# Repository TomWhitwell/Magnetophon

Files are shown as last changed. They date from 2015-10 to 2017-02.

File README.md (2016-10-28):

# Magnetophon  
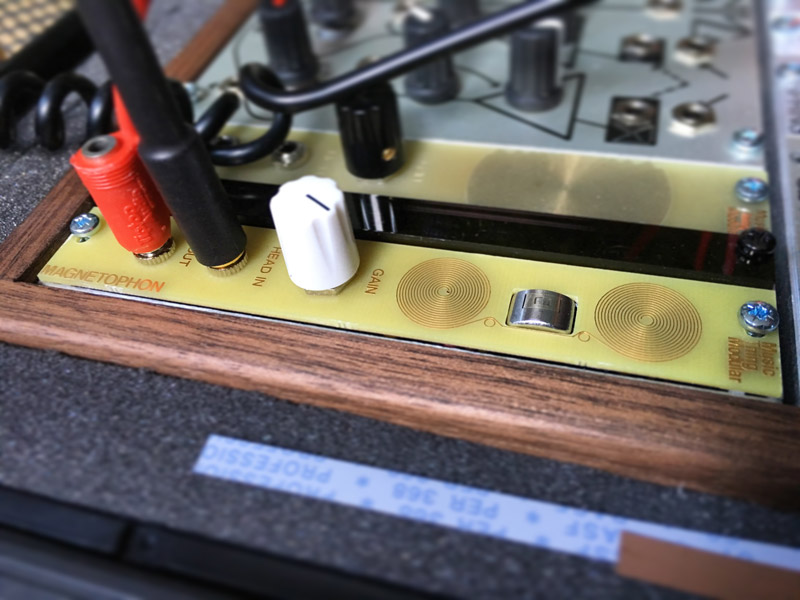
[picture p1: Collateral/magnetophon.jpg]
  
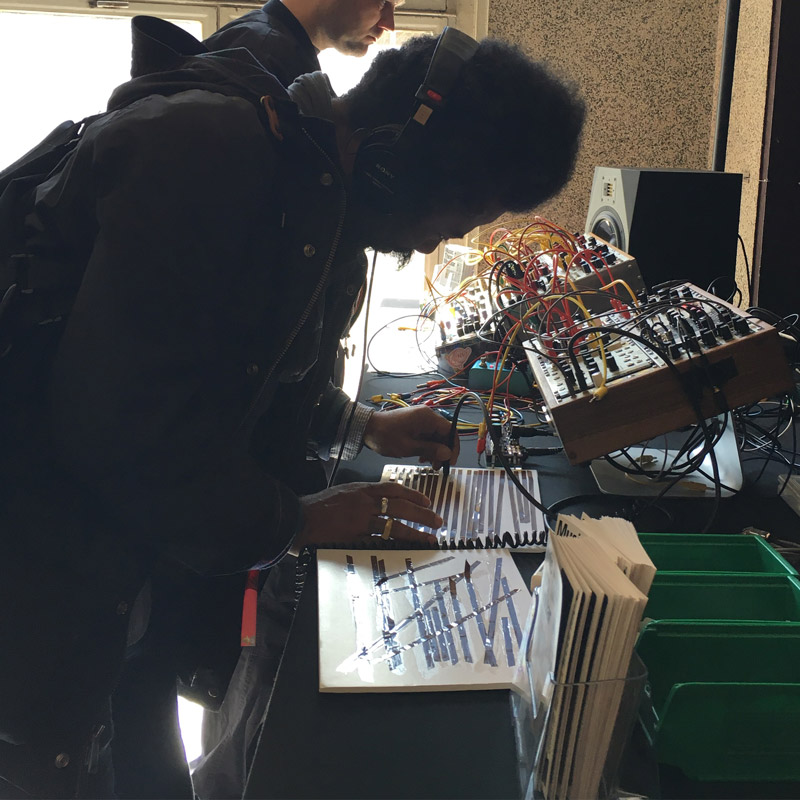
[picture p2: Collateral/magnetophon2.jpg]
    

With a mono cassette head in the panel and a NAB equalised ampli er circuit, Magnetophon is a cassette player without the transport mechanism. Try rubbing old cassette tapes on the panel, or attach a head on a wire to recreate Nam June Paik’s
Random Access or Laurie Anderson's Tape Bow Violin. 

[Schematic](https://github.com/TomWhitwell/Magnetophon/blob/master/Collateral/Magnetophon_schematic.pdf)

[Magnetophon is in this video from SuperBooth16 in Berlin](https://youtu.be/UVMrQejVZlw?t=4m26s) 

[Magnetophon vs Nagra audio torture test. The Nagra sounds better(!) but it gets fun when the Magnetophon head starts moving](https://soundcloud.com/musicthing/nagra-v-magnetophon)

BOM: 

- 2 x Thonkiconn Sockets 
- 1 x 50k Alpha Potentiometer (from Thonk, with bushing)  
- 1 x 10 pin 5x2 Euro power header 
- 1 x TL072 op amp 
- 1 x CTH1M MONO cassette playback head
- 2 x Poly Fuses (100ma blow or higher) 
- 2 x 1N4001 diodes 
- 1 x 47uf Electrolytic Capacitor* 
- 2 x 10uf Electrolytic Capacitors* 
- 2 x 100nf Ceramic Capacitor 
- 1 x 15nf Polybox Capacitor
- 1 x 200k resistor 
- 1 x 3.6k resistor 
- 1 x 2.2k resistor 
- 1 x 470R resistor 
- 2 x 200R resistor 
- Notes: 
- C7 is NOT required but a space is left on the board in case you have any oscillation in the first op amp stage. 
- *Electo caps should be short - 7mm tall - to fit between the boards. Otherwise, you can mount them on the back if you are careful of polarity. 

Status: 
- May 2016: Rev 1 (= Proto 2 with silkscreen tweaks) should be good to build. 
- Proto 2 works well. 
- Proto 2 designed and sent to fab 
- Proto 1 used for 4 days straight at SuperBooth 
- Proto 1 built, needed extra capactitor to kill huge ultrasonic oscillation
- Not verified 
- January 2016 Prototype sent for manufacture 
- October 2015 Designed 

Named after the [AEG Magnetophon](http://www.aes.org/aeshc/docs/recording.technology.history/tape.html), the first commercial tape recorder, revealed at the 1935 Radio Fair in Berlin. 

  
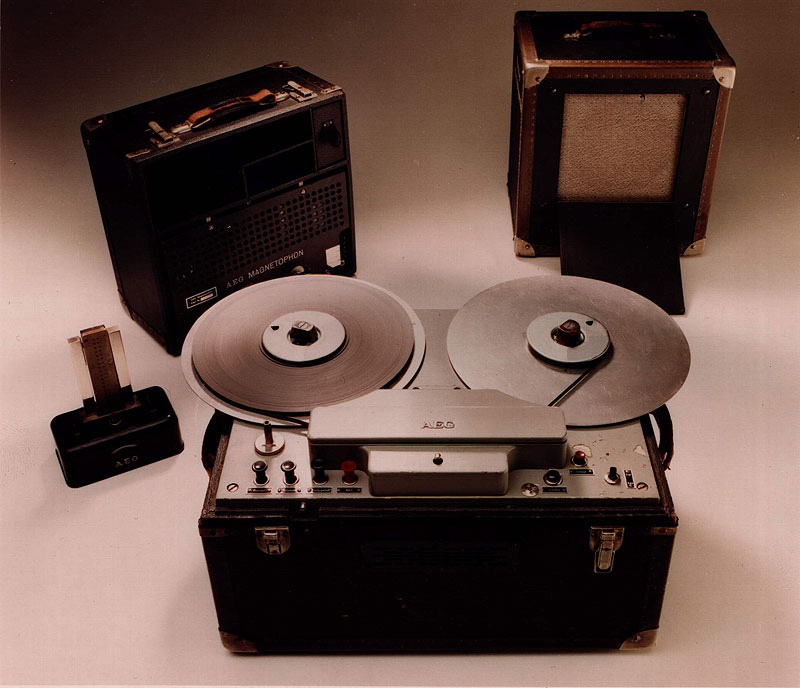
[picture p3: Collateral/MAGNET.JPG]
  
([Image via AES](http://www.aes.org/aeshc/docs/recording.technology.history/tape.html))

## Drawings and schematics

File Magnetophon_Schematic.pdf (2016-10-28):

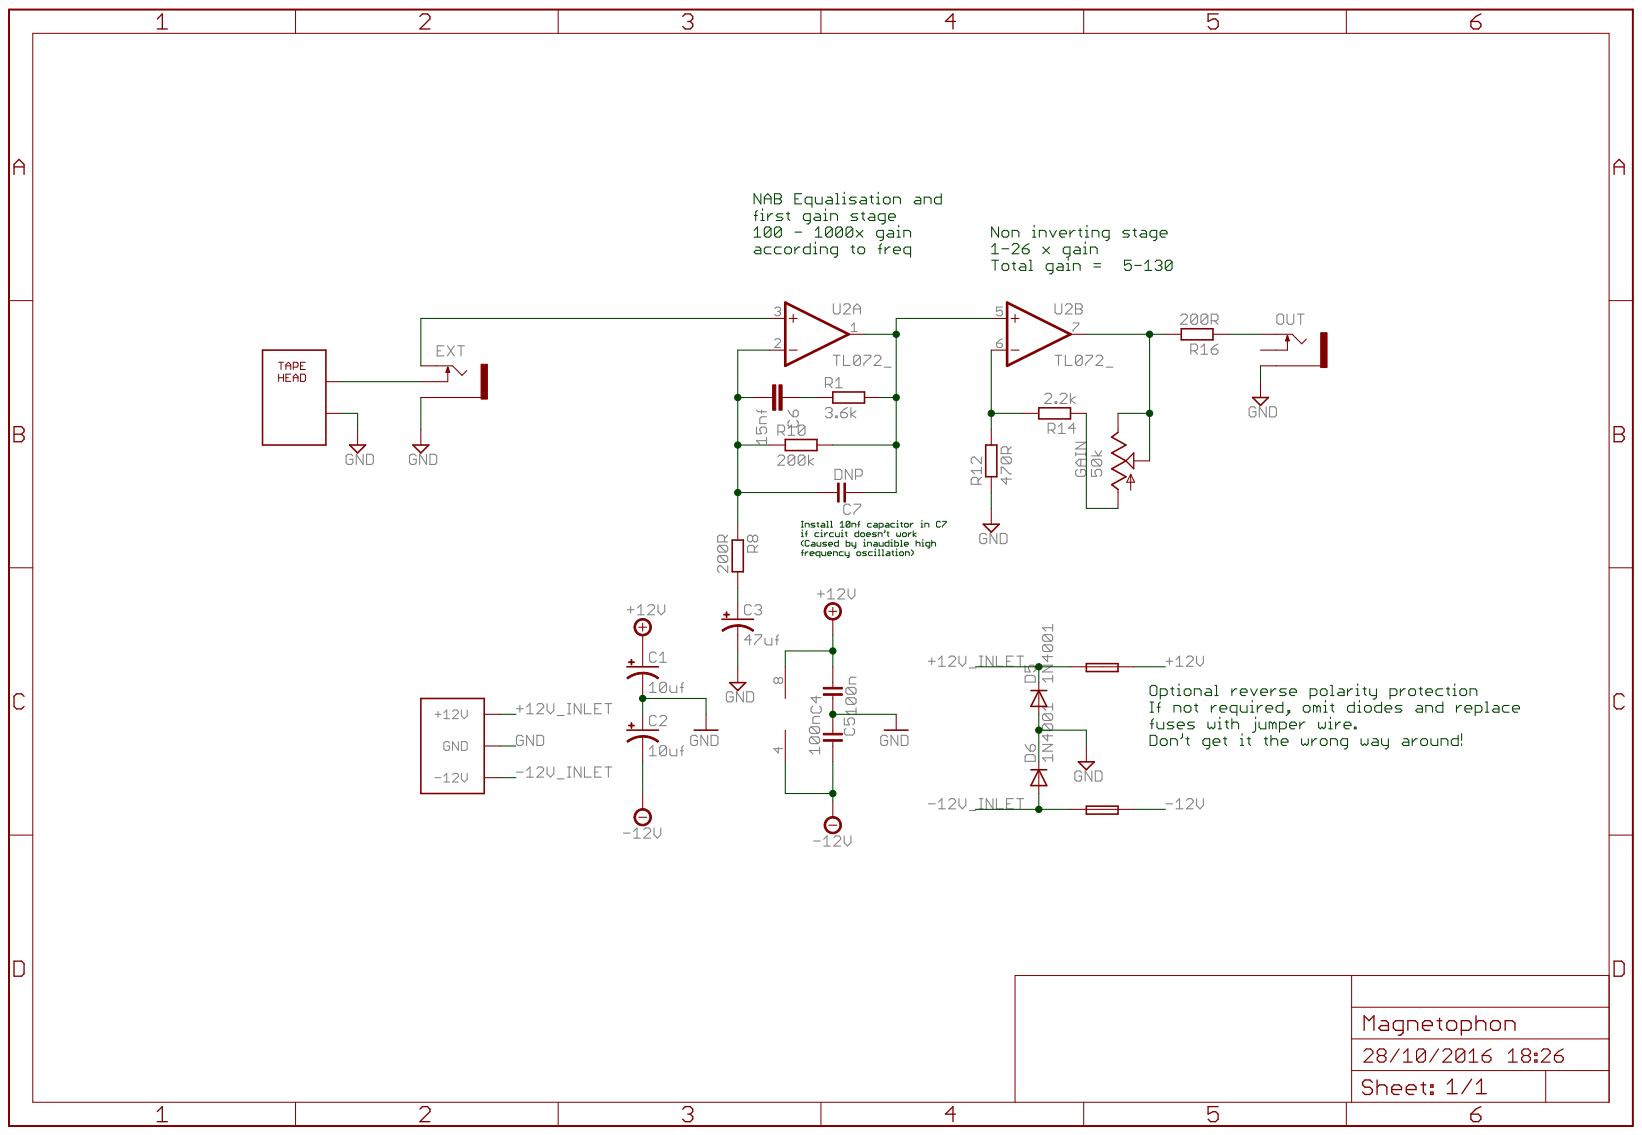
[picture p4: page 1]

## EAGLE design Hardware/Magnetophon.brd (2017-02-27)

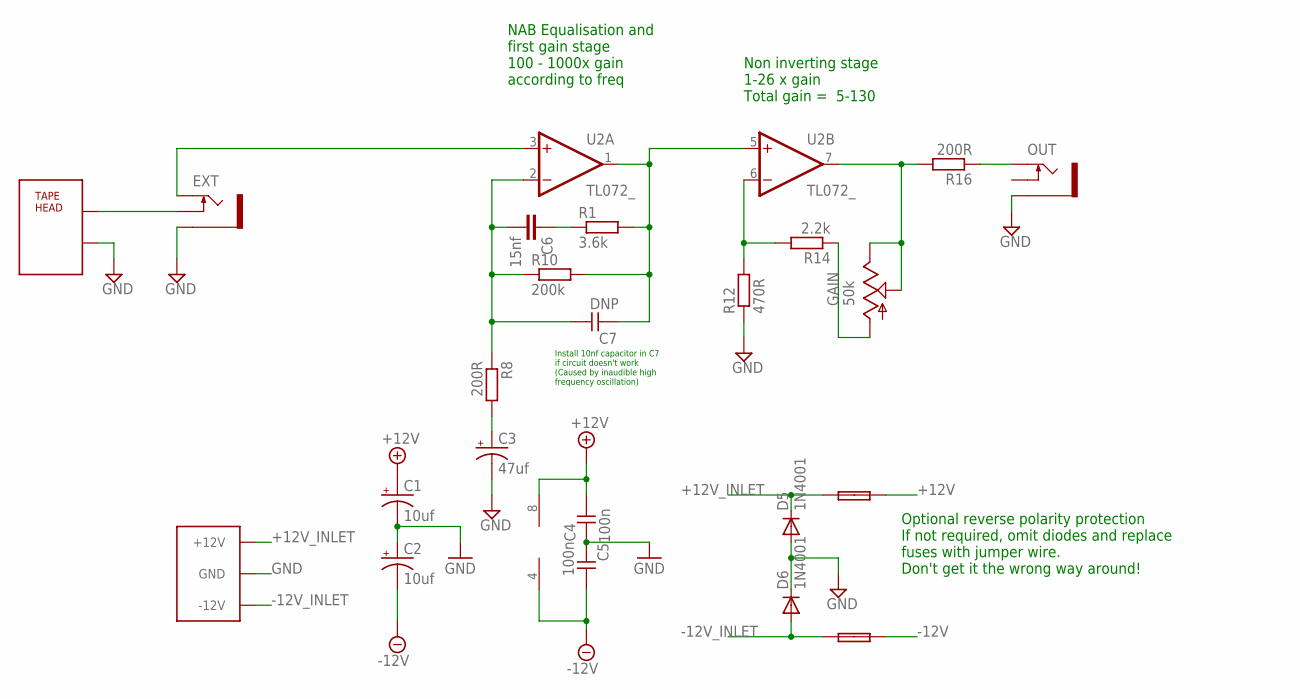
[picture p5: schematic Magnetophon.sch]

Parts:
1: FUSE; C050H075X075
C1, C2: 10uf; CPOL-RADIAL-10UF-25V
C3: 47uf; CPOL-RADIAL-10UF-25V
C4, C5: 100n; C050-024X044
C6: 15nf; C050-030X075
C7: DNP; C050-024X044
D5, D6: 1N4001; DO41-10
EXT: THONKICONNNEW; WQP-PJ301M-12_JACK
FUSE: FUSE; C050H075X075
GAIN: 50k; EVUF
OUT: THONKICONNNEW; WQP-PJ301M-12_JACK
R1: 3.6k; 7MM_RESISTOR
R8, R16: 200R; 7MM_RESISTOR
R10: 200k; 7MM_RESISTOR
R12: 470R; 7MM_RESISTOR
R14: 2.2k; 7MM_RESISTOR
U2: TL072_; DIL08
U$1: MONO_CASSETTE_HEAD
U$2: EURO_POWER_LOCK; EURO_PWR_HEADER_LOCK

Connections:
+12V: 1.2, C1.1 (+), C4.1, U2.8 (V+)
+12V_INLET: 1.1, D5.C, U$2.POS1 (+12V), U$2.POS2 (+12V)
-12V: C2.2 (-), C5.1, FUSE.2, U2.4 (V-)
-12V_INLET: D6.A, FUSE.1, U$2.NEG1 (-12V), U$2.NEG2 (-12V)
FROMHEAD: EXT.P$2_SWITCH (SWITCH), U$1.P$1
GND: C1.2 (-), C2.1 (+), C3.2 (-), C4.2, C5.2, D5.A, D6.C, EXT.P$3_SLEEVE (SLEEVE), OUT.P$3_SLEEVE (SLEEVE), R12.1, U$1.P$2, U$2.GND1 (GND), U$2.GND2 (GND), U$2.GND3 (GND), U$2.GND4 (GND), U$2.GND5 (GND), U$2.GND6 (GND)
unnamed: C6.2, C7.1, R8.1, R10.1, U2.2 (-IN)
unnamed: C7.2, R1.2, R10.2, U2.1 (OUT), U2.5 (+IN)
unnamed: GAIN.1 (A), R14.1
unnamed: R12.2, R14.2, U2.6 (-IN)
unnamed: C3.1 (+), R8.2
unnamed: GAIN.2 (S), GAIN.3 (E), R16.2, U2.7 (OUT)
unnamed: C6.1, R1.1
unnamed: OUT.P$1_TIP (TIP), R16.1
TOAMP: EXT.P$1_TIP (TIP), U2.3 (+IN)

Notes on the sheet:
NAB Equalisation and first gain stage 100 - 1000x gain according to freq
Non inverting stage 1-26 x gain Total gain = 5-130
Optional reverse polarity protection If not required, omit diodes and replace fuses with jumper wire. Don't get it the wrong way around!
Install 10nf capacitor in C7 if circuit doesn't work (Caused by inaudible high frequency oscillation)

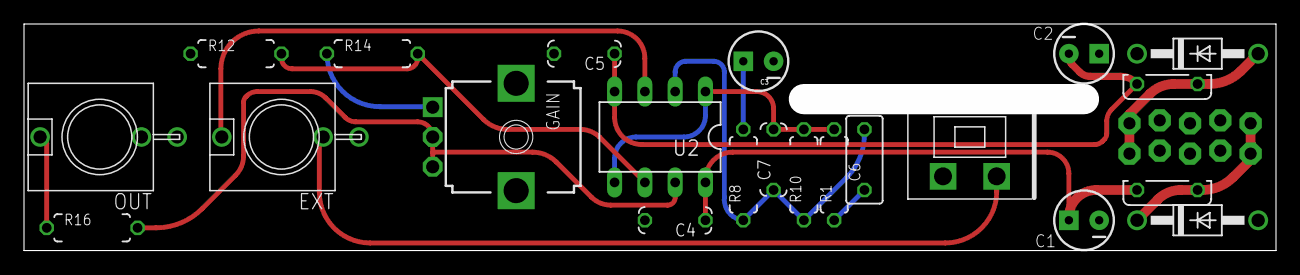
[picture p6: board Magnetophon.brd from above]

Board: 4 copper layers, 105.0 x 19.0 mm, 23 parts (1 on the bottom side), 15 nets.

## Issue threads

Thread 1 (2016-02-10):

huge 100khz oscillation

TomWhitwell, 2016-02-10:
cured by 10n cap between pin 1&2 of op amp

Closed 2016-05-03.

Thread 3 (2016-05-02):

Prototype 2 PCB: Silkscreen issues

TomWhitwell, 2016-05-02:
No electro cap sizes
fuze markings are messy

Closed 2016-05-03.

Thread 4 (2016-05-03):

Issues with rev2 PCB

TomWhitwell, 2016-05-03:
Build with
R12 2.2k
R14 2.2k
Pot 50k
No c7
= Works well

Closed 2016-05-03.

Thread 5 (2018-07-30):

MTM Magnetophon

boombipbass, 2018-07-30:
I just soldered together a Megnetophon, so far Ive succeeded the Mikrophonie and the Music thing,
I am sure I've checked the making the module manual quite close but it doesn't generate any sound from my tape loops I've stuck on a piece of wood with the 2nd head, also the 1st head is not responding nor do I get a feedback hum from other modules form the output.

How could I check with a multimeter if the module is getting power in the circuitry?

Best bbb

boombipbass, 2018-07-30:
Ok well Ive just learned that you should atleast never put a just soldered module in your Eurorack..

Oups haha. Well atleast Ive learned something on my own, but now to think, I do have a multimeter or are there better solutions?

Best bbb

TomWhitwell, 2018-07-30:
If the module is completely dead, check the op amp chip is getting power - look at the data sheet (google TL072) and see which pins need +v and -v. Put the black probe on -v and the red probe on +v and you should see around 23-24volts. Check the chip is correctly oriented.

boombipbass, 2018-07-30:
Is this the data sheet? https://github.com/TomWhitwell/Magnetophon/blob/master/Magnetophon_Schematic.pdf

How do I know which is 5+ and -6 of the 8 pins? Its faceing the right way aswell as the OpAmp Holder.

Also how can I check if the TapeHead/minijack male is working with my Multimeter?

Thanks for helping me ^-^

Love your stuff!

TomWhitwell, 2018-07-30:
It’a on page 5 here : http://www.ti.com/lit/ds/symlink/tl072.pdf

(NOT page 4, that’s the tl071)

boombipbass, 2018-07-30:
Ah yes by following the copper route on the backside I already found out that R17 connected with 7 and thus which 5 must be since that one connected to the OpAmp nr. 1 in the schematics, wow learning new things here 🗡

boombipbass, 2018-07-30:
Strange that a black probe must be on the - and a red on the + since the ribbon is otherwise in color :)

boombipbass, 2018-07-30:
is it AC of DC?

boombipbass, 2018-07-30:
Nope not with AC nor with DC its getting 23/24 volts. On my multimeter set to 20 V.
I've checked with the OpAmp holder aswell as with the OpAmp itself :- (

boombipbass, 2018-07-30:
I do have to say I havent put it in my modular system, because I read thats stupid and I should actuaklly use a Bench power supply or some sort?

boombipbass, 2018-07-30:
I am sure all connections are soldered good though

boombipbass, 2018-07-30:
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

boombipbass, 2018-07-30:
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
Also on modulargrid it says this about the magnetophon which i dont udnerstand?

TomWhitwell, 2018-07-30:
That just means nobody has put the power specs into modular grid - it draws around 25mA or less on each rail

boombipbass, 2018-07-30:
Ok thats good to know, then the only thing I am wondering, do I need a Bench power supply to test DIY kits or not?

And should I recheck the module in the case with the IC to see if it gets 24 volts, it has been in the case and no smoke or explosions so thats a good thing :)

boombipbass, 2018-07-30:
Ok well checked it with Power on and still no Votlage, any solution? :)

realitycontrol, 2018-07-30:
If you're measuring between the +V and -V pin on the OpAmp using the 20V DC setting on your multimeter (as stated above); you will not get a reading.

You want to be using the 200V setting when you are expecting anything over 20V.
If using the 20V setting you could separately measure the + and - pins to ground.

zerojardins, 2020-04-29:
As I can see on the pictures of your board, you misplaced both fuses with the two 100n capacitors (C4 & C5)

hope that helps

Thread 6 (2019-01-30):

Omit panel mounted tape head?

dujoducom, 2019-01-30:
Would there be any negative effects of omitting the panel mounted tape head (just not soldering it on)? I'd like to make the wand instead, only have one tape head, and see basically no reason why I personally would utilize the panel mounted one.

derridada, 2020-07-11:
so - I put this together and the tape head simply doesn't seem to work, but the Head input does. I'm thinking of pulling the tapehead and building a wand. Did you build it omitting the tapehead on the panel? If so - how did it work out?

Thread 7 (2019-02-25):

Powering the module

Terbijn, 2019-02-25:
Hi,

I'm putting together an installation and don't have a proper Eurorack power supply at hand right now. Do you think the module could be powered with batteries? If so, is there something you recommend? The exhibition would be on for 7 days and I think the module would be in active use for not more than 3 hours during that time.
Also, are there instructions for building the wand?

Thank you very much!

Best wishes,
Oliver

TomWhitwell, 2019-02-26:
I've never tried it, but you might be able to use two 9v batteries back to back

Closed 2019-02-26.

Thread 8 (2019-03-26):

Magnetophon playback

metalthrow, 2019-03-26:
I have a Magnetophon with an external playback head. When rubbing the tape head across tape stuck to a sheet of foamcore or hard paper, I've tried both, it just sounds like the back of a credit. I'm wondering if anyone has experimented with this and knows if it is possible to obtain the cassette's actual sounds on it when manually pushing the head on to the tape?

TomWhitwell, 2019-03-26:
Hi, Sorry to hear that. I've tested it both with cassette tape and with 1/4" tape from a Nagra.
Clearly the 1/4" tape is much easier, because it's a single mono signal going one direction along the tape.
However, I did get it to work roughly with cassette tape, although the signal was substantially lower in output, and your have four simultaneous tracks -  left & right x 2 (backwards & forwards) on each bit of tape, which can quite quickly become noise.
A secondary issue was that when I tried it with spoken word tapes (language cassettes) I quickly realised that for every inch of speech there might be 3-4 inches of silence, which makes the whole thing a bit tricky.
You're getting roughly 2 inches of tape per second of sound - which should give an idea how fast to move the head.

metalthrow, 2019-03-27:
Thank you for the reply so promptly. I'm going to try out some 1/4'' tape and see fi that helps. I also noticed in the demo video there something on top the tape , did you glue it to the paper? also does foamcore vs. paper make a difference

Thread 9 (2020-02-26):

Tape Wand

tetsugakusha66, 2020-02-26:
Hi Tom!
I'm having a big issue with my Magnetophon.
The tape head in the module itself works all right, but as soon as I plug in anything into the Head In jack, it's noise city.
I soldered the tape head to a 3m long patch cable and when it's plugged in the ground noise is massive. I'm assuming this is a ground noise problem, because when I touch nearly anything on my desk, the noise is attenuated slightly. The tape head on the wand functions correctly so I don't think that I have soldered it in backwards.
Could this be due to the length of the tape head wand or the fact that I used a patch cable instead of a guitar cable?
I tried to populate the DNP spot with a 10nf cap, but to no avail.
Any advice you could offer would be greatly appreciated!

snoopyart, 2020-06-25:
Exactly the same issue for me. I also used a patch cable (high quality though, with shielding). Also tried the 10nf cap. Also no way to get it working with the wand. No idea. Checked all solder points etc. but the module itself works perfectly fine with the internal head... Any help appreciated! THX!

magnesi, 2020-07-23:
Same here. Any help would be hugely appreciated as I'm trying to use it for a college project.

TomWhitwell, 2020-07-24:
Re: ground noise problems for @magnesi @snoopyart @tetsugakusha66
I connected mine using (from memory) a balanced cable - i.e. two internal connectors and one shield. The internal connectors went from tip/ring on the socket to the two pins on the tape head. The orientation doesn't seem to matter. The shield is connected at the socket end. At the tape head end I tried to connect it to the metal frame of the tape head, but I'm not sure this was super successful. I found it very hard to solder to the tape head body, so I stripped a bit of the shield and put it next to the tape head body, then held it in place with heat shrink.
I don't if this will solve your problems, but it's worked OK for me.

magnesi, 2020-07-25:
Thanks Tom

esoterydactyl, 2022-06-11:
Very happy to have found this issue open, as I have been driving myself absolutely crazy this afternoon trying to understand what I've done wrong with the kit!  I'll see if I can work out a balance cable.  If this turns out to be the solution, we should consider updating documentation to recommend it!

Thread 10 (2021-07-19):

Some notes from build experiences

mroystonward, 2021-07-19:
Hi not actually an issue but it does address several existing issues (open and closed) and therefore might be of use to some.

I've successfully built this module using these tape-heads - https://www.aliexpress.com/item/33005387634.html?spm=a2g0s.12269583.0.0.513062e8RFe37r

To fit in the panel, I removed the metal guide/fork and then bent the rest of the metal around the tape head body. I soldered trimmed off component legs to the tape head legs, and then mounted in the PCB/panel before soldering. The bent around metal frame helps it sit in place but I'm going to use a dab of epoxy to make it a bit more solid.

I did have no end of trouble at first. It didn't *sound* like oscillation but the extra capacitor definitely helped.

There is a little interference/hum when holding tape near the head but it's acceptable.

For the tape wand, I again removed the guide forks and bent the rest of the metal around the tape head. I used stereo/2-core shielded cable, as recommended in an issue above. Each core was soldered to a tape head leg with the shield trapped and soldered between the extra-bent-around metal and the tape head. I then used excessive amounts of heat-shrink (descending in size to fit both the head and cable) to keep it all secure, neat, insulated, etc. On the other end, a 3.5mm mono jack plug with one of the cores wired to the tip and both the other core and shield wired to the sleeve connection.

Basically, the wand was unusable when I first tried with mono cable but works fine with a stereo cable. Again, a bit of hum when actually holding the tape head but it's all workable.

Anyway, hope this helps others and thanks for making the module open source etc.

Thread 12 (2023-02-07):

No Audio, Bad Humming

acoostix, 2023-02-07:
I've received and built a Magnetophon kit from Thonk. PCB v1.1

I fully traced out all components against the schematic found on this git - while some components are not present on the board, the components that are are connected are connected correctly. Good solders. TL072 is mounted correctly, electronlytic caps are mounted correctly.

I can confirm that the TL072 is reading 24 volts at its VCC pin.

When the module is plugged in to my Intelligel performer 104 withcable coming out of case (to have module as far away as possible from other modules) I get no sound off of the tape head. Only a loud intermittent buzz based on handling. It sounds distorted and a bit lower than a mains hum.

I see that the schematic says - install C7 if the circuit doesn't  work: This doesn't make a difference in my case.

Plugging in my wand gives the same results.

Is it possible that the tape head needs chassis grounding? Most tape heads are mounted to a chassis, but as far as I can tell - this one is "floating" in the IC socket- no screws holding it to the case of a reel-reel tape deck etc.

I did try googling, but perhaps I've missed something ;P

acoostix, 2023-02-08:
Closing this with the fix I found:

By grounding the casing of the tapehead back to the case PSU groundrail, problem was fixed. I also swapped out the TL072 - I'm not sure switching ICs would have made a difference, though, as the TL072 that came with the kit works perfectly in another circuit.

Hopefully this helps someone!

Closed 2023-02-08.

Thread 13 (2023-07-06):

Very weak sound

jojo-monk, 2023-07-06:
Bonjour,

je viens de finir de construire le module, il fonctionne mais le son est vraiment très faible, même avec le gain au maximum.
J’ai remplacer le condensateur C6 par un 22nf au lieu de 15nf, car je n’avais que celui-ci sous la main, est-ce que ça peut être la cause du problème ?
Ou alors la tête de lecture ? J’ai utilisé celle-ci : https://fr.aliexpress.com/item/1005004626148845.html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

jojo-monk, 2023-07-06:
English traduction : Hello,

I just finished building the module, it works but the sound is really very low, even with the maximum gain.

I replaced the C6 capacitor with a 22nf instead of 15nf, because I only had this one on hand, can that be the cause of the problem?

Or the reading head? I used this one:

TomWhitwell, 2023-07-07:
Hi a few questions

1. What tape are you using to test the head - if you use a piece of commercial stereo cassette tape - there are 4 x channels at each point on the tape, overall each is very low. I've had best results from a mono 1/4 inch recording
2. Are you using the tape head on the panel or on a separate wire / 'wand' - it's easier to get a good contact between tape and read with a separate head
3. Is that a stereo tape head? I haven't used those - perhaps that has lower output than a mono head - maybe there is some way to wire the two channels together?
4. I don't think the 22/15nf will make a big difference

jojo-monk, 2023-07-07:
I used stereo cassettes with a separate playback head, but indeed it is a stereo playback head, since it has 4 pins, I welded only 2, I will try to weld the 2 channels together, and try to recover 1/4-inch strips.

Thanks

jojo-monk, 2023-07-07:
J’ai testé en connectant les 2 canaux ensemble, et avec une bande plus large, c’est un peu mieux, mais le signal est encore trop faible… est-ce que ce n’est pas un problème d’impedance ? La tête que j’ai à une impédance de 260 ohm ? C’est peut-être trop… y a-t-il moyen d’adapter le module en changeant quelques résistances ou condensateurs ?

jojo-monk, 2023-07-07:
I tested by connecting the 2 channels together, and with a wider band, it's a little better, but the signal is still too weak... isn't it an impedance problem? The head I have at an impedance of 260 ohm? It may be too much... is there a way to adapt the module by changing some resistors or capacitors?

TomWhitwell, 2023-07-07:
I'm afraid I don't know - the schematic is here but I can't help beyond that

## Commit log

2015-10-07 First upload
    [magnetophone.brd, magnetophone.sch]
2015-10-08 Starting layout
    [magnetophone.brd, magnetophone.sch]
2015-10-11 First pcb layout
    [magnetophone.brd, magnetophone.sch]
2015-10-12 Start panel
    [magnetophone_panel.brd, magnetophone_panel.sch]
2015-10-16 panel design
    [magnetophone.brd, magnetophone_panel.brd]
2015-10-17 panel finished
    [magnetophone.brd, magnetophone.sch, magnetophone_panel.brd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]
2015-10-17 Design complete - to do: Checking hole size for playback head
    [magnetophone.brd, magnetophone_panel.brd]
2015-10-18 filename changes
    [playback.brd, playback.sch, playback_panel.brd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]
2016-01-25 Add via to ground panel artwork
    [Magnetophon.brd, Magnetophon.sch, Magnetophon_panel.brd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]
2016-01-26 Prototype 1 finalised design and gerbers
    [Magnetophon.brd, Magnetophon.sch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]
2016-04-07 add 10n cap and reroute
    [Magnetophon.brd, Magnetophon.sch]
2016-04-09 improved layout and curves
    [Magnetophon.brd, Magnetophon.sch]
2016-04-09 Prototype 2 Gerbers
    [Magnetophon.drills.xln]
2016-05-03 Small board tweaks, fixes #1, fixes #2, fixes #3, fixes #4
    #1 and #2 fixed by improved layout, #3 and #4 with tweaks here
    [Magnetophon.brd, Magnetophon.sch]
2016-05-05 Rev 1 Gerbers
    [Magnetophon.drills.xln, Magnetophon_panel.drills.xln]
2016-06-04 upload schematic
2016-08-04 Fix issue with trace crossing cutout
    [Magnetophon.brd]
2016-08-20 update details
    [Magnetophon.brd]
2016-08-20 Revised Panel, renamed as MAGNETOPHON
    [Magnetophon_panel.drills.xln]
2016-08-20 Tidy up
    [Magnetophon_panel.drills.xln]
2016-08-22 Update panel eagle file to remove old logo
    [Magnetophon_panel.brd]
2016-09-08 Update board design
    [Magnetophon.brd]
2016-09-08 Version 1.1 Gerbers, fix cutout/trace issue
    [Magnetophon.drills.xln]
2016-10-28 update R12 to improve gain
    [Magnetophon.brd, Magnetophon.sch]
2016-10-28 Schematic image
    [Magnetophon.sch]
2016-10-28 Reroute to avoid space under socket
    [Magnetophon.brd]
2017-02-27 1.2 version, removed old Gerber files
    [Magnetophon.brd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]

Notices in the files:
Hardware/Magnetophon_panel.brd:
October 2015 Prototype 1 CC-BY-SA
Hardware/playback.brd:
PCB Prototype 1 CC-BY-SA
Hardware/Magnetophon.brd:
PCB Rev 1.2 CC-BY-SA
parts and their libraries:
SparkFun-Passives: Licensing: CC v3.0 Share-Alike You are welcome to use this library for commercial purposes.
